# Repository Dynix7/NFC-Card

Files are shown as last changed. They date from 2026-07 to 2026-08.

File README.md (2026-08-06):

# NFC Business Card
This is my design for a personal NFC Business Card that I've put my name, title, and some things I like. It features a NFC chip so that you can scan it using your phone and it'll bring you to my GitHub or anything else that you want. TThere is also a QR code that you can scan with your phone that will bring you to my GitHub page. It also has a variety of footprints on the back for reference.

# Why I Made It
I firstly wanted something that I could put my name and to illustrate my skills in programming, PCB design, etc. I also wanted to create art with this and express myself by putting the things I like the most. On the back I included footprints and a ruler for helping my visualize component sizes and general use.

# PCB Photos

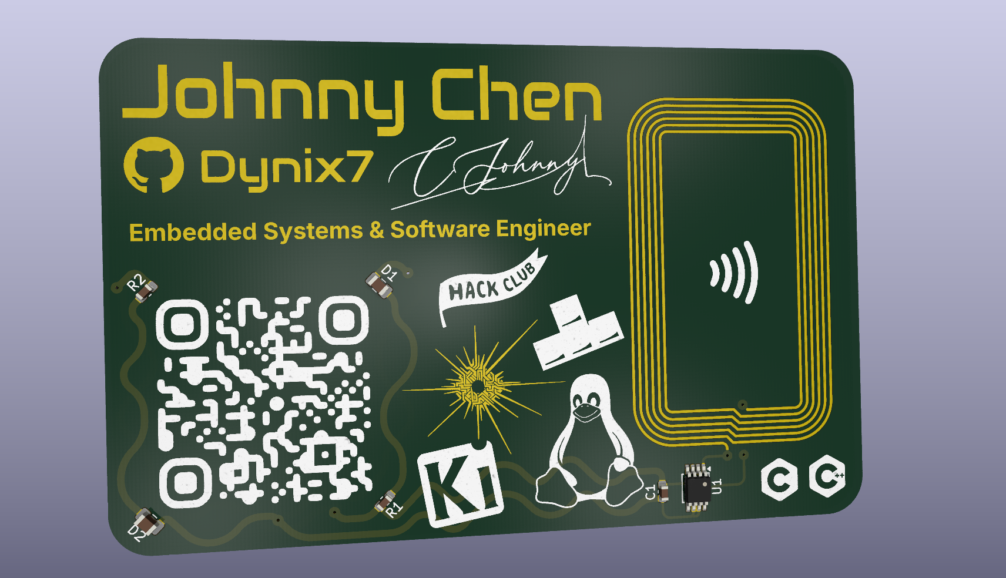
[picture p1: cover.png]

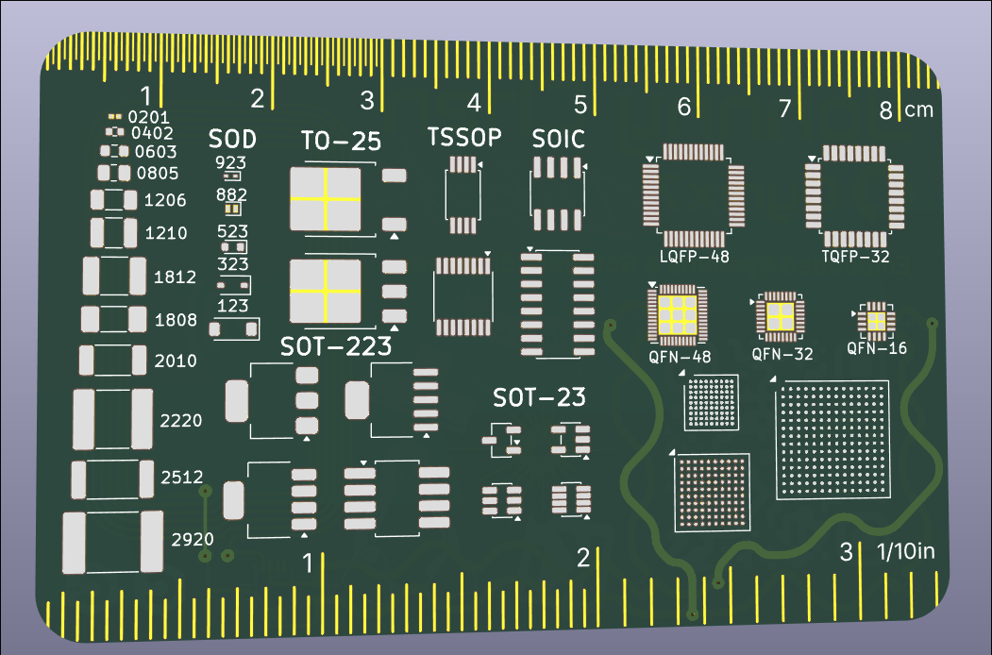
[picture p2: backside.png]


# PCB Editor Photos
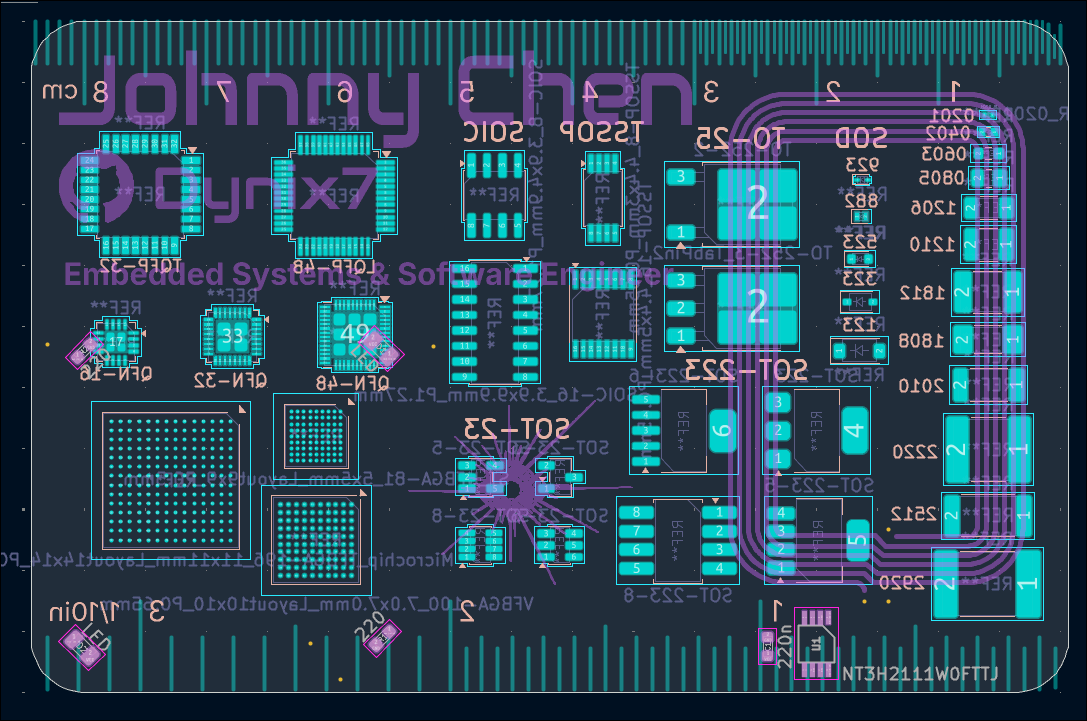
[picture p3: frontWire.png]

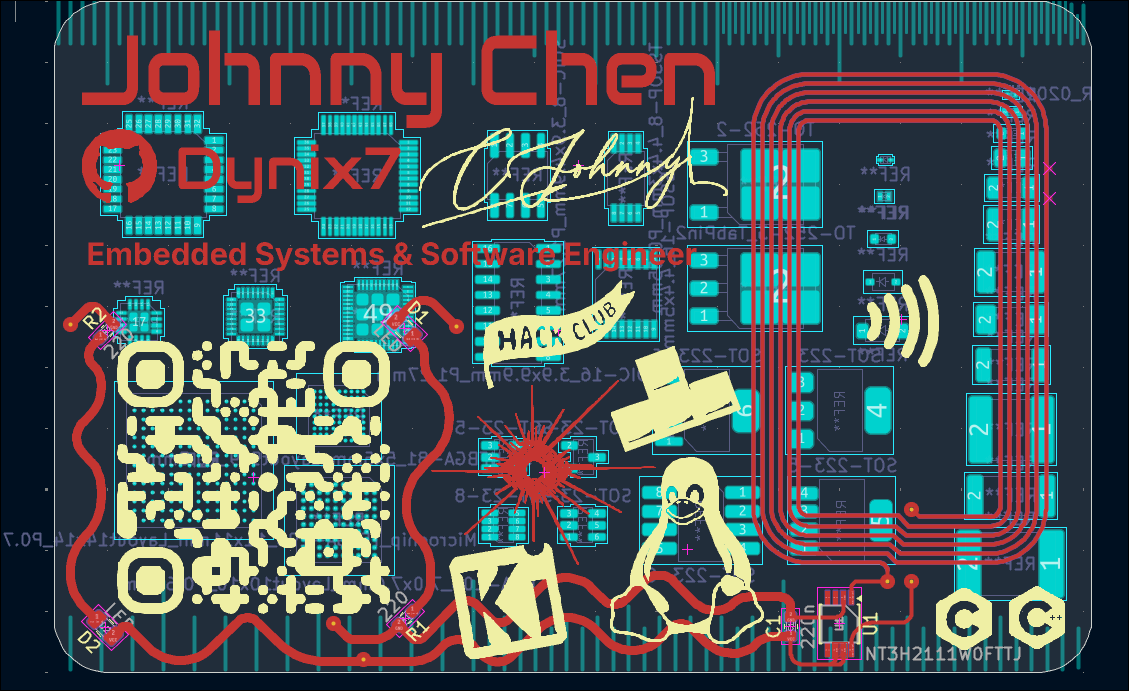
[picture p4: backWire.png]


# Schematic Photos
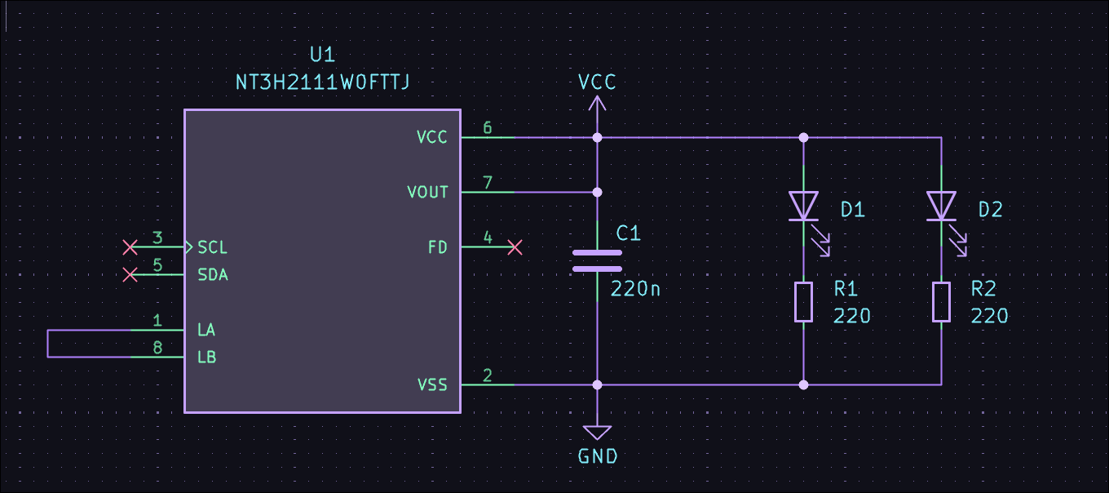
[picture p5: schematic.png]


# BOM
|Name |Purpose |Total Cost (USD)|Link |Distributor |
|---|---|---|---|---|
|NT3H2111W0FTTJ |NFC Chip |$1.37 |https://www.digikey.com/en/products/detail/nxp-usa-inc/NT3H2111W0FTTJ/5872979 |Digikey |
|220ohm Resistor |Resistor for LEDs|$0.12 |https://www.digikey.com/en/products/detail/yageo/RT0603FRE10220RL/21619987 |Digikey |
|Green LEDs |Indicator for PCB|$0.75 |https://www.digikey.com/en/products/detail/liteon/LTST-S220KGKT/386875 |Digikey |
|220nf Capacitor |Stabilize Power  |$0.56 |https://www.digikey.com/en/products/detail/murata-electronics/GCM188R71E224KA55D/1765183|Digikey |
|JLCPCB Costs |Main PCB |$21 | |JLCPCB |
|Shipping+Fees+Tarrifs| |$15.12 | |Digikey + JLCPCB|

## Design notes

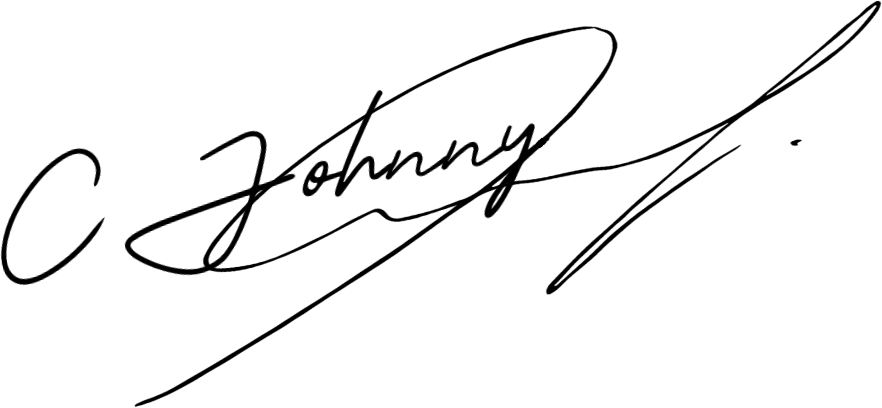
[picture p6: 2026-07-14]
assets/sig3.png

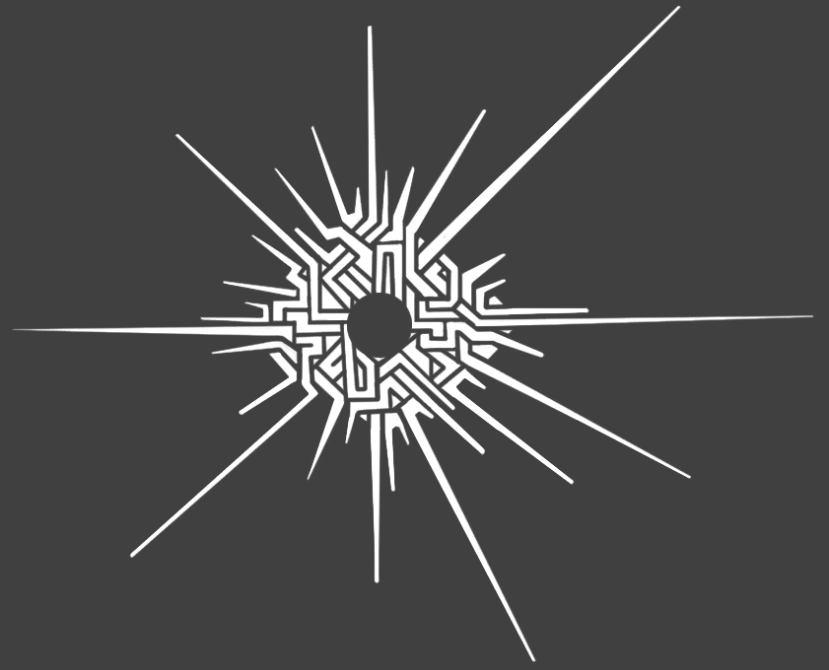
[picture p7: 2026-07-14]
assets/outerWilds.png

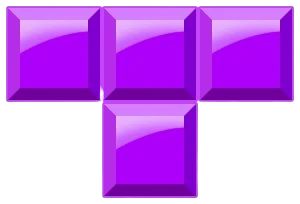
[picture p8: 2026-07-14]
assets/tetris.jpg

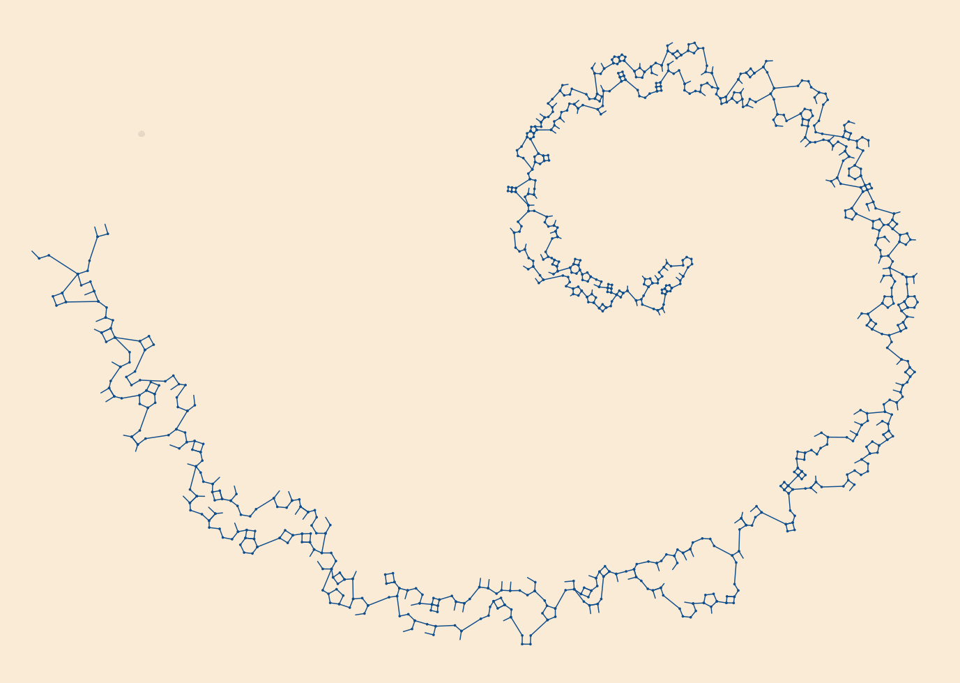
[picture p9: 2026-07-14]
assets/photo.png

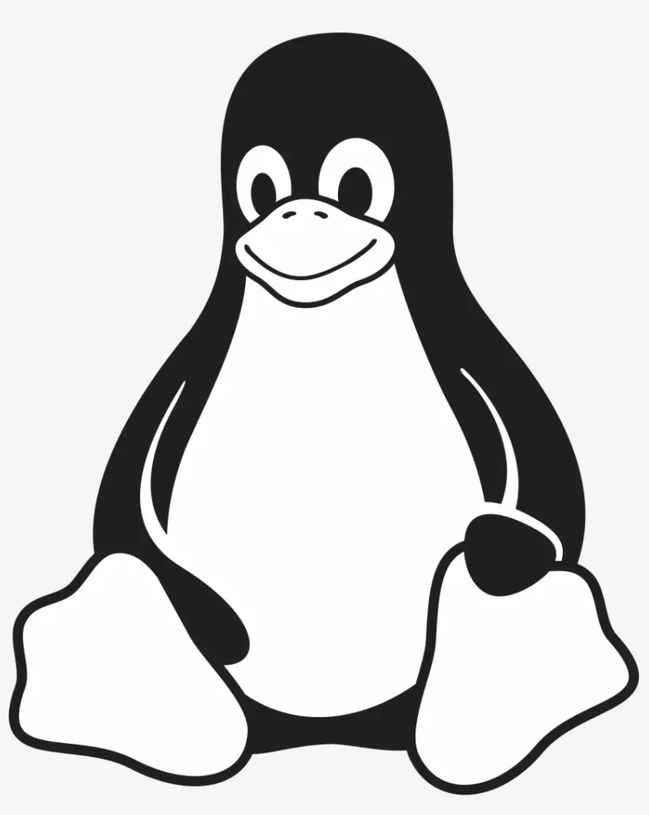
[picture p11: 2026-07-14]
assets/linuxFr.jpg

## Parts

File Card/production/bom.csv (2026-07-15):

Designator | Footprint | Quantity | Value | LCSC Part #
C1 | 0603 | 1 | 220n
D1, D2 | 0805 | 2 | LED
R1, R2 | 0603 | 2 | 220
R_0201 | 0201 | 1 | 0201
U1 | TSSOP-8_3x3mm_P0.65mm | 1 | NT3H2111W0FTTJ

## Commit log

2026-07-11 Schematic and Parts
    [Card.kicad_pcb, Card.kicad_sch]
2026-07-11 Part of PCB
    [Card.kicad_pcb, Card.kicad_sch]
2026-07-14 Front Side Decorations
    [Card.kicad_pcb]
2026-07-15 Add Gerbers
    [bom.csv, designators.csv, positions.csv]
2026-07-23 Added BOM
    [BOM.csv]
2026-07-23 update BOM
    [BOM.csv]
2026-08-06 Bom in readme
